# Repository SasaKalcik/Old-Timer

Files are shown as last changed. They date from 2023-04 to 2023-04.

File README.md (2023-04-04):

# Old-Timer

## 3D printed Arduino based interval timer display
Old Timer is a 3D printed wall mountable interval timer, intented for HIIT (High Intensity Interval Training). This is a DIY-project for a 64x64 RGB LED matrix display with a speaker and an interface, powered by an Arduino microcontroller board.

[VIDEO](https://youtu.be/OxGpQ27moh4)

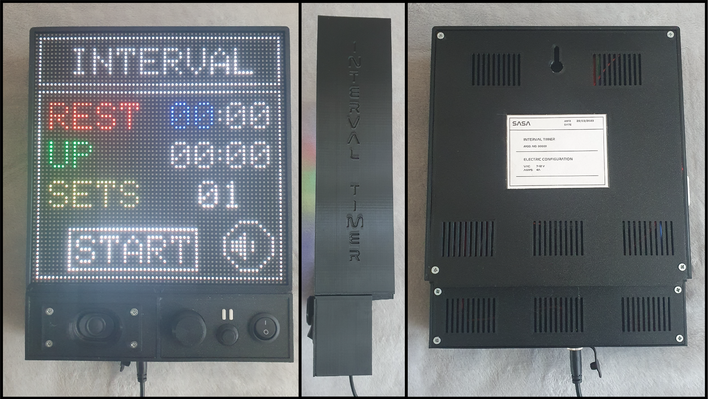
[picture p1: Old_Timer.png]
Old Timer


## Hardware
This project started out with parts from an Arduino starter kit, 3D printed parts and a 64x64 RGB LED matrix. For an affordable minimalistic parts list (without the 3D printed case) I would recommend the following:

- 1 x AC-DC power adapter 5.0 V / 4.0 A  
- 1 x ELEGOO Mega R3 2560 Project Starter Kit 
- 1 x (64x64) RGB LED matrix
- 1 x DFPlayer mini MP3 player
- 1 x TF-card (DFPlayer supports up to: 32 GB)

Complete list of Old Timer's "electronic guts":

- 1 x AC-DC power adapter 5.0 V / 4.0 A  
- 1 x Female DC Threaded Barrel Jack Panel Adapter (or any connector suitable for plug of AC-DC power adapter)
- 1 x MEGA 2560 R3 Controller Board
- 1 x Prototype Shield Board Kit for Arduino Mega \*
- 1 x (64x64) RGB LED matrix 
- 1 x DFPlayer mini MP3 player
- 1 x TF-card (DFPlayer supports up to: 32 GB)
- 1 x 3 W 8 &Omega; Speaker 
- 1 x rotary encoder with switch function (on press down)
- 1 x tactile switch (6 x 6 x 4.3 mm) 
- 1 x ON/OFF toggle round rocker switch 
- 1 x 1 k&Omega; resistor
- DuPont cables

\* *Note: The stock shield board kit for the Arduino Mega has female pins for DuPont cable connections. These can be desoldered and replaced with male pin connectors, since the DATA IN cable of the RGB LED matrix board comes with a female to female pin cable. Alternatively you can use DuPont cable connections and ommit the shield altogether. Also the FDPlayer can be mounted on the shield.*

## 3D printed case

The 3D printed case printed with PLA filament is split into a top and lower part. The top part is connected with the matrix display with 6 (M3 x 10 mm) screw bolts (red dots in the picture). The matrix display provides the structural strength, so the case walls can be very thin (2 - 3 mm). The lower body containing the speaker and buttons can be swapped/upgraded in the future. The bottom and top bodies are connected with 6 (M4 x 15 mm) screw bolts and M4 hex nuts (green dots in the picture). The case is sealed with two covers which can be screwed on using 8 (M3 x 10 mm) bolts (red dots in the picture). There is a mount for the Arduino board and a cover for the speaker which also can be fastened with (M3 x 10 mm) screw bolts. I have also made a case for the mini switch button (4 parts). It's a cheap alternative to buying a switch button with housing. The top part of the button can be screwed on the housing containing the mini switch to make a nice clicking action. Two hex nuts can be printed instead of one to better secure the housing and top part of the button. 

3D printed case assembly parts:

- [8 x 3D printed parts](/STL_files) 
- 23 x (M3 x 10 mm) screw bolts 
- 6 x (M4 x 15 mm) screw bolts
- 6 x (M4 9 mm diameter) flat washers 
- 6 x M4 hex nuts

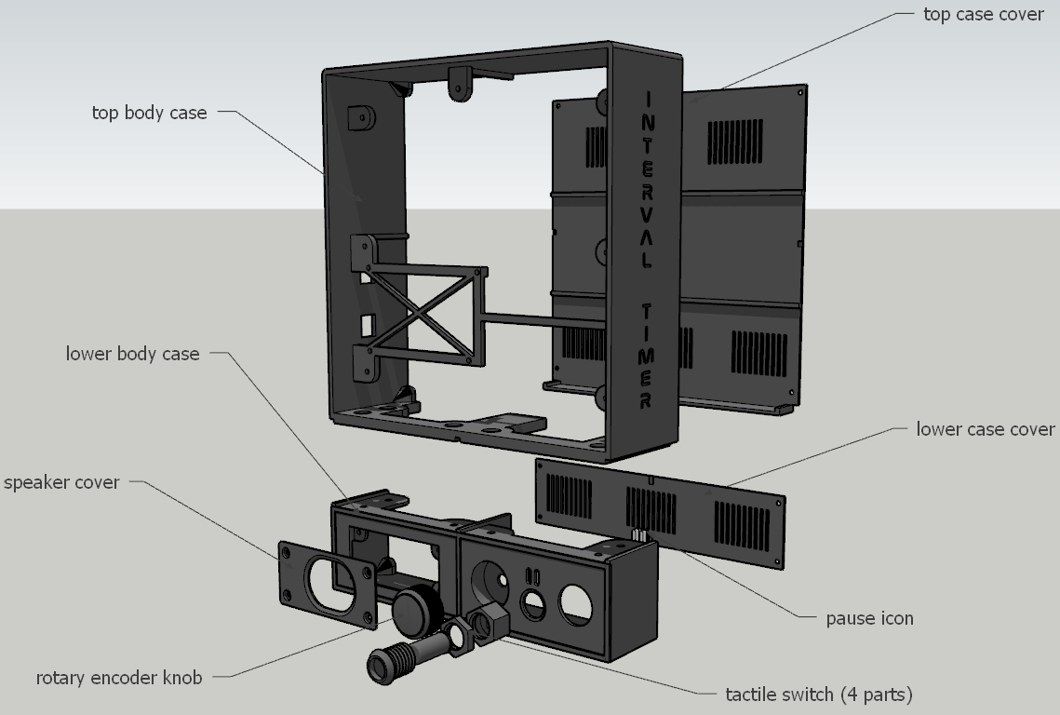
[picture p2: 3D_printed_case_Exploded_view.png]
exploded view of 3D printed case


## Wiring 

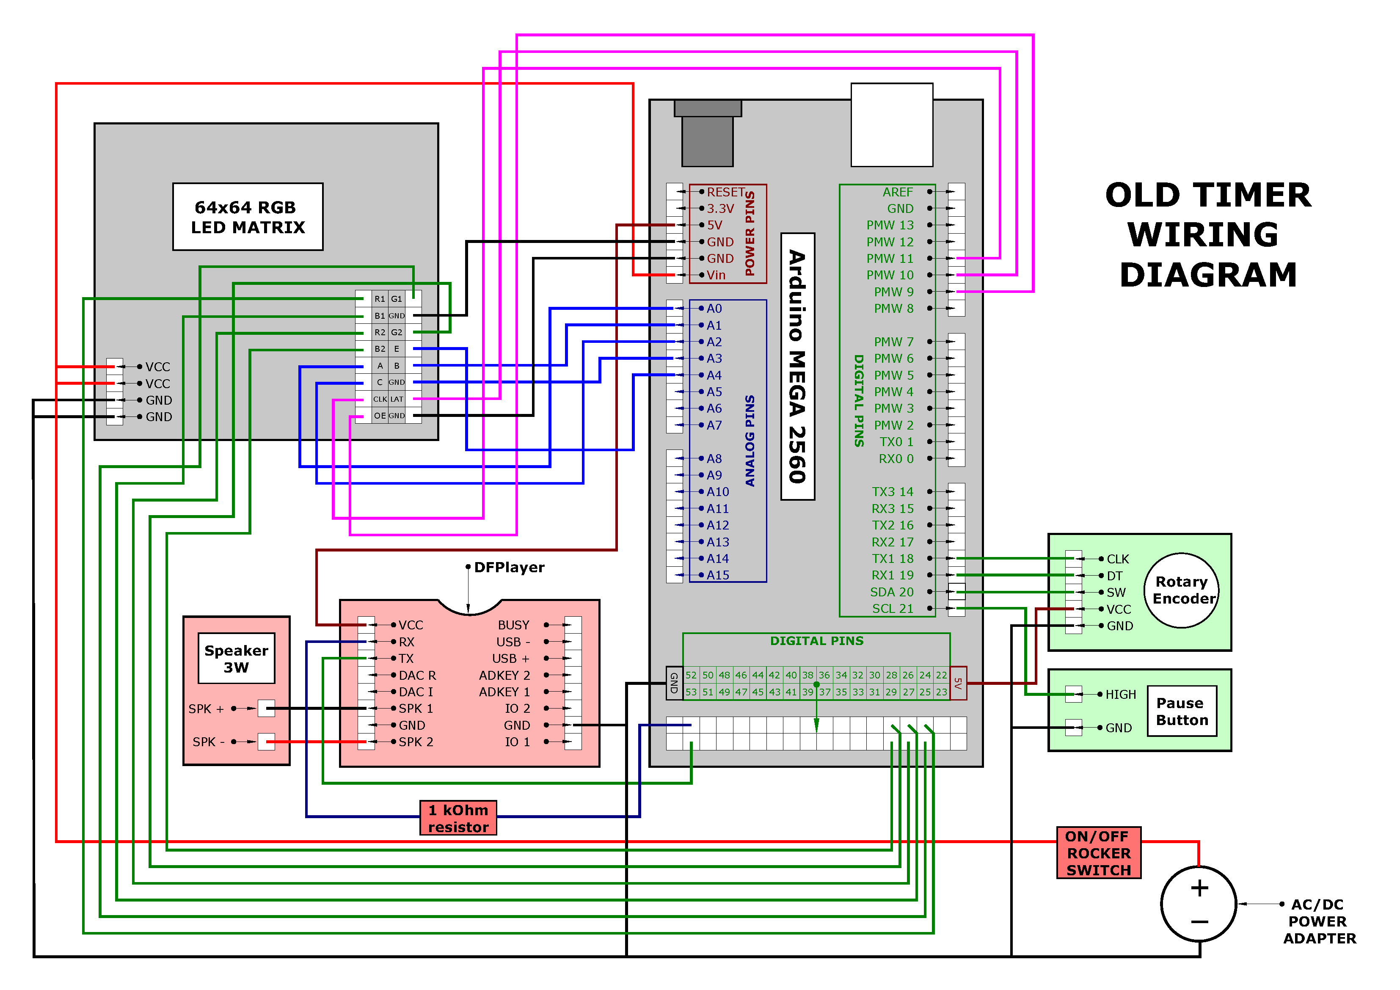
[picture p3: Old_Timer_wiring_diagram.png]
Old Timer wiring diagram


For clarity the wiring can be split down into serveral parts:

### Power supply
The 64x64 RGB LED matrix alone requires a 5 V regulated DC power input and 4 A with all LEDs on at full brightness. However, a 5V 4A is sufficient to power to entire setup. For testing, the Arduino controller board can be powered directly from a computer using an USB connector without an external power supply. An ON/OFF toggle round rocker switch is added to switch the power supply on and off. 

### RGB LED Matrix 
The 64x64 RGB LED Matrix Panel has 4096 full-color RGB LEDs, which can be controlled independently. These kind of displays are designed to be driven by FPGAs (field-programmable gate arrays) and dont have any built in pulse-width modulation control. An Arduino MEGA 2560 R3 Controller Board is used since the RGB LED display needs 13 GPIOs (general-purpose input/output pins) to be controlled. Other microcontrollers (Raspberry Pi) with large enough speed and memory can be used. The Mega 2560 works great for this project, but higher speed controllers are needed to drive this display in "full glory". Alternatively smaller LED Matrix displays are available (for example a 1024 bright RGB LED display on a 32x32 grid). The matrix panel has two IDC (insulation-displacement contact) connectors DATA IN and DATA OUT to cascade displays. The Arduino isn't powerful enough however to control larger displays.

DATA IN IDC signal pins connected to Arduino MEGA 2560, L if left and R is right side of connector pins:

|DATA IN L|Arduino pins| DATA IN R|Arduino pins|
|:---:|:---:|:---:|:---:|
|R1|24|G1|25|
|B1|26|GND|GND|
|R2|27|G2|28|
|B2|29|E|A4|
|A|A0|B|A1|
|C|A2|D|A3|
|CLK|11|LAT|10|
|OE|9|GND|GND|

Power interface:
|RGB LED Matrix|AC-DC power adapter|
|:---:|:---:|
|2 x +5V | positive terminal|
|2 x GND | negative terminal|

### Interrupts: rotary encoder and push buttons

The interface of the interval timer is a rotary encoder and a push switches. The rotart enocoder has a built in push switch, which is used to navigate the menu. A mini tactile switch serves to pause the interval timer. Both inputs are connect via interrupt pins to the Arduino. Pins 2,3,18,19,20,21 can be used on the Arduino Mega 2560 as external interrupt pins.

|rotary encoder|mini push switch|
|--|--|
|<table> <tr><th>pin</th><th>Arduino</th></tr><tr><td>CLK</td><td>18</td></tr><tr><td>DT</td><td>19</td></tr><tr><td>SW</td><td>20</td></tr><tr><td>VCC</td><td>5V</td></tr><tr><td>GND</td><td>GND</td></tr></table>|<table><tr><th>pin</th><th>Arduino</th></tr><tr><td>HIGH</td><td>21</td></tr><tr><td>GND</td><td>GND</td></tr></table>|

### DFPlayer mini MP3 player

The DFPlayer is a MP3 player module with a TF card/MicroSD slot. The MP3 player can be powered by the 3.3 V or 5 V output of the Arduino. After testing the DFPlayer module in a mono circuit with a 3 W 8 &Omega; speaker-setup I found that module doesn't work reliably with 3.3 V input. With 5 V input, the Arduino doesn't seem to provide enough current when changing the volume to max. I've ordered and tested three MP3 modules. Two modules worked perfect, one was faulty. An external power supply with a max voltage of 5 V is ideal to reduce noise and increase the power from the speaker. However it is not necessary since the MP3 player won't be operating at max volume for an extented period of time in this project. I would recommend ordering a few MP3 player modules to serve as backup, since they are very cheap. The DFPlayer  has a 3 W amplifier. A speaker with 4 &Omega; or more impedance can also be used for a louder maximum volume.

The pins on the DFPlayer are not indicated so be mindful of the orientation. The signal pins of the DFPlayer mini module are not 5V tolerant so a voltage divider (1 k&Omega; resistor) is added between the RX signal pin and the Arduino. 

The DFPLayer pins connected to the Arduino:

|DFLPLayer|Arduino|
|:---:|:---:|
|VCC|5V|
|RX|52|
|TX|53|
|SPK1|SPK+|
|GND|GND|
|SPK2|SPK-|

## Code

The [code](/Old_Timer.ino) for the interval timer is for a menu system. [Here](https://youtu.be/OxGpQ27moh4) is a video of the Old Timer in action. 

When turned on a startup animation plays and a menu is displayed. In this menu you can set the following:

- UP, duration of workout in minutes and seconds
- REST, duration of rest in minutes and seconds
- SETS, the number of sets of UP/REST 
- Volume of the speaker (0 - 30)

After the everything is set, START is pressed --> interval cycles are run --> return to the selection menu. 

Detailed comments are provided in the code, but I'll quickly run throught the code. You will need several libraries for the display and MP3 player:

- Graphics library for the RGB LED matrix: [DFRobot_RGBMatrix.h](https://github.com/DFRobot/DFRobot_RGBMatrix)
- library for MP3 player: [DFRobotDFPlayerMini.h](https://github.com/DFRobot/DFRobotDFPlayerMini)  
- library for serial communication: [SoftwareSerial.h](https://docs.arduino.cc/learn/built-in-libraries/software-serial)
- library for I2C communication: [Wire.h](https://www.arduino.cc/reference/en/language/functions/communication/wire/)
- library for calculation: [math.h](https://www.tutorialspoint.com/arduino/arduino_math_library.htm)

The *loop()* function waits for interrupts from the rotary encoder : *read_encoder()* and *buttonPush_encoder()*. It checks whether the cursor postion is changed through rotation of the encoder: *refreshMATRIX == true*. The loop also checks for the selection of a menu item due to a button push: *refreshSelection == true*.

```ruby
void loop() 
{
  if(refreshMATRIX == true) 
  {
    updateMATRIX(); 
    if(menu_RESTm_selected == true...) // refresh cursor on interrupt
    {
     // do nothing if no menu item is selected
    }
    else
    {
      updateCursorPosition(); 
    }
    refreshMATRIX = false; 
  }

  if(refreshSelection == true) // refresh selection on interrupt
  {
    updateSelection(); 
    refreshSelection = false; 
  }
}
```

The functions: *updateCursorPosition()*, *updateSelection* and *updateMATRIX* then update the display by updating a part of the screen. The display resfreshes much smoother by updating parts of the matrix than rewriting the entire screen, since these RGB LED matrix displays usually are driven by FPGAs. 

Finally I have written functions which display time (*printTime*), loading bars (*loadingBar*), the full interval cycle (*intervalTimerScreen*) and text (*displayText*). These function use the DFRobot_RGBMatrix grahpics library and comments are provided in the [code](/Old_Timer.ino).

## Credits and References

This project wouldn't have been possible without the amazing tutorials and projects available online. So I would like to thank everyone for all the great idea's and information. I'm happy to share their links as a shout-out:

[Wiring DFPlayer Mini](https://circuitjournal.com/how-to-use-the-dfplayer-mini-mp3-module-with-an-arduino)

[DFR0499 64x64 RGB LED matrix](https://wiki.dfrobot.com/64x64_RGB_LED_Matrix_-_3mm_pitch_SKU_DFR0499)

[Advanced menu system with rotary encoder for Arduino/STM32](https://www.youtube.com/watch?v=CnS0PuDJybA&t=323s&ab_channel=CuriousScientist)

[Arduino Button Debounce Tutorial](https://www.youtube.com/watch?v=jYOYgU2vlSE&ab_channel=educ8s.tv)

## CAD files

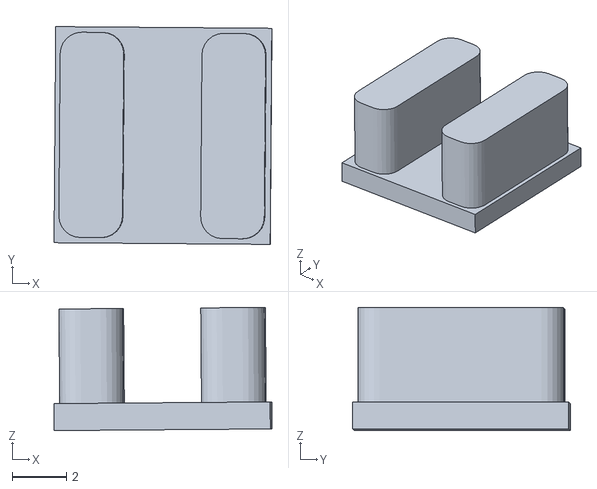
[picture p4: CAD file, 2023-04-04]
STL_files/pause_button.stl
8.07 x 8.06 x 4.56

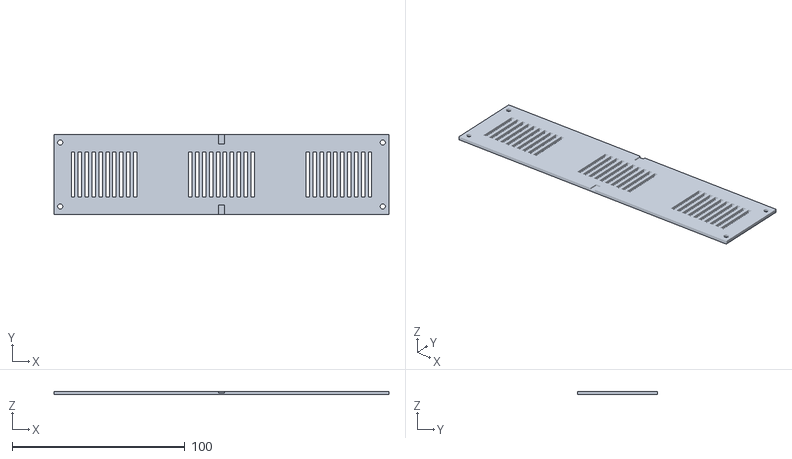
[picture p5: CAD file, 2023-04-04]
STL_files/lower_case_cover.stl
194.0 x 46.2 x 2.00

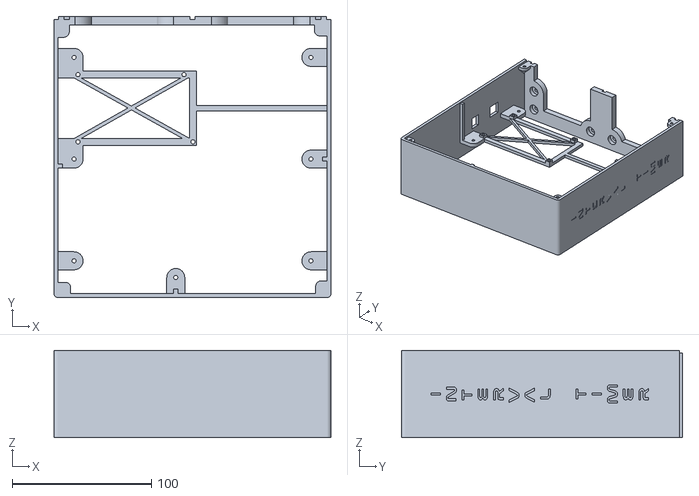
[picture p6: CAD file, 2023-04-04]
STL_files/top_body_case.stl
198.8 x 201.8 x 62.5

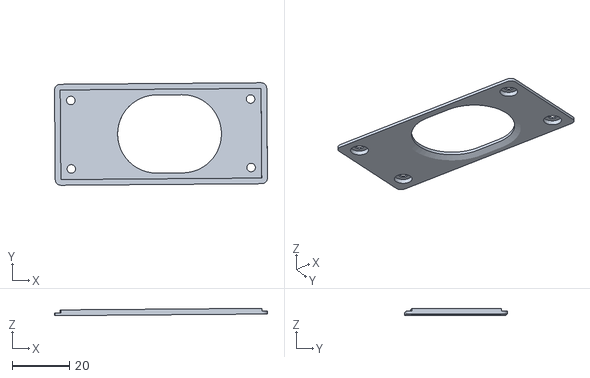
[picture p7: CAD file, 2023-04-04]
STL_files/speaker_cover.stl
74.6 x 35.9 x 2.56

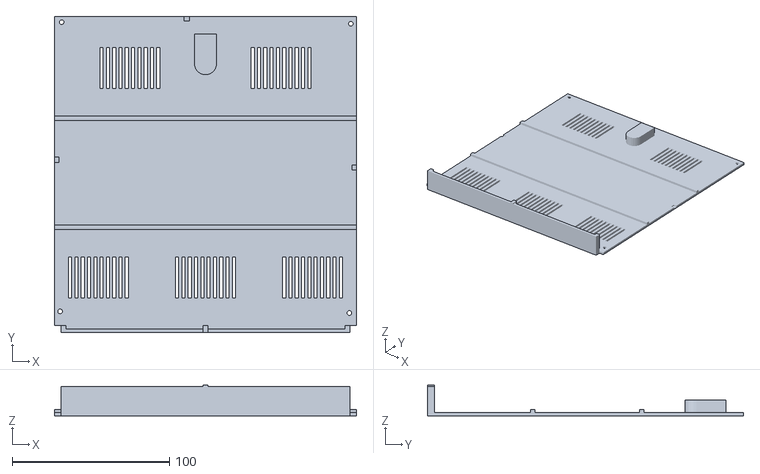
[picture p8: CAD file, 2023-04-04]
STL_files/top_case_cover.stl
192.0 x 200.8 x 19.5

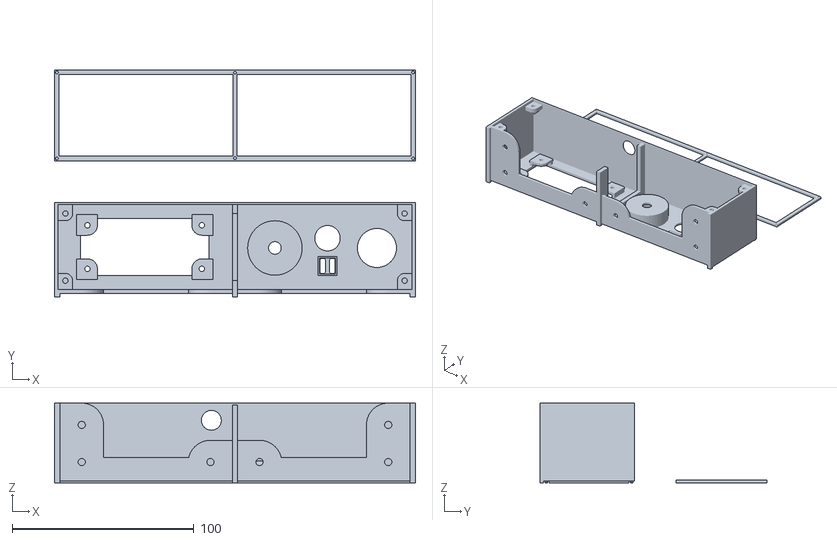
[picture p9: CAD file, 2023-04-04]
STL_files/lower_body_case.stl
198.8 x 125.0 x 44.0

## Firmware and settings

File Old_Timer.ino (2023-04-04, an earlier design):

// libraries
#include <DFRobot_RGBMatrix.h>    // graphics library for RGB LED matrix board
#include <Wire.h>                 // library for I2C communication
#include <math.h>                 // library for calculations
#include <DFRobotDFPlayerMini.h>  // library for MP3 player
#include <SoftwareSerial.h>       // library for serial communication

// Defining MATRIX BOARD pins and variables connected to elegoo mega 2560 
#define OE    9                 // Output enable
#define LAT   10                // Latch
#define CLK   11                // Clock
#define A     A0                // A line selection
#define B     A1                // B line selection
#define C     A2                // C line selection
#define D     A3                // D line selection
#define E     A4                // ground?
#define WIDTH 64                // matrix board 64 px width
#define HIGH  64                // matrix board 64 px height
// set MATRIX BOARD pin settings & size
DFRobot_RGBMatrix matrix(A, B, C, D, E, CLK, LAT, OE, false, WIDTH, HIGH); 

// Define ROTARY ENCODER pins
// Note: Arduino MEGA 2560 interrupt pins: 2, 3, 18,19,20,21 (20,21 not available when I2C is used)
#define ENC_CLK 18            // encoder CLK used for rotation and diretion detection
#define ENC_DT 19             // encoder DT used for rotation and diretion detection
#define ENC_SW 20             // Click Button
#define BTN_Pause 21          // Pause Button
// Statuses for the ROTARY ENCODER
unsigned long _lastIncReadTime = micros(); 
unsigned long _lastDecReadTime = micros(); 
int _pauseLength = 25000;
int _fastIncrement = 5;
volatile int counter = 0;

// Define MP3 player pins and create object for MP3 player
SoftwareSerial mySoftwareSerial(53, 52);  // (TX, RX)
DFRobotDFPlayerMini MP3_Player;           // create MP3_Player object

// MENU variables
// Note: if menu item is selected/deselected colour changes blue/white
int8_t menuCounter = 0;            // counts menu items (0-6) = (RESTm,RESTs,UPm,Ups,SETS,START,VOLUME)
int8_t menu_RESTm_Value = 0;       // rest minutes (0-59)
int8_t menu_RESTs_Value = 0;       // rest seconds (0-59)
int8_t menu_UPm_Value = 0;         // UP minutes (0-59)
int8_t menu_UPs_Value = 0;         // UP seconds (0-59)
int8_t menu_SETS_Value = 1;        // number of sets (1-99)
int8_t menu_start_Value = 0;       // start button
int8_t menu_volume_Value = 20;     // volume (0/10/20/30)
volatile bool flagPause;           // pause button flag

int8_t menu_RESTm_Value_old = menu_RESTm_Value;       // rest minutes (0-59)
int8_t menu_RESTs_Value_old = menu_RESTs_Value;       // rest seconds (0-59)
int8_t menu_UPm_Value_old = menu_UPm_Value;           // UP minutes (0-59)
int8_t menu_UPs_Value_old = menu_UPs_Value;           // UP seconds (0-59)
int8_t menu_SETS_Value_old = menu_SETS_Value;         // number of sets (1-99)
int8_t menu_start_Value_old = menu_start_Value;       // start button
int8_t menu_volume_Value_old = menu_volume_Value;     // volume (0/10/20/30)

// enable/disable selected menu item on start up
bool menu_RESTm_selected = false;   
bool menu_RESTs_selected = false;
bool menu_UPm_selected = false;
bool menu_UPs_selected = false;
bool menu_SETS_selected = false;
bool menu_start_selected = false;
bool menu_volume_selected = false;
bool refreshMATRIX = true;      // refreshes display on startup
bool refreshSelection = false;  // refreshes selection (white to blue) on start up

void setup() 
{
  // Steer input pin to known state using built in pullup 20 k Ohm resistor
  pinMode(ENC_CLK, INPUT_PULLUP);   // RotaryCLK
  pinMode(ENC_DT, INPUT_PULLUP);    // RotaryDT
  pinMode(ENC_SW, INPUT_PULLUP);    // ButtonSW (Button)
  pinMode(BTN_Pause,INPUT_PULLUP);  // Pause Button

  // Attach interrupt pins    
  attachInterrupt(digitalPinToInterrupt(ENC_CLK), read_encoder, CHANGE);       
  attachInterrupt(digitalPinToInterrupt(ENC_DT), read_encoder, CHANGE);
  attachInterrupt(digitalPinToInterrupt(ENC_SW), buttonPush_encoder, FALLING);  
  attachInterrupt(digitalPinToInterrupt(BTN_Pause), buttonPush_Pause, FALLING);

  // Settings for MP3 player
  mySoftwareSerial.begin(9600);             // Initialize USB serial port for debugging
  Serial.begin(115200);                     // Initialize serial port for DFPlayer Mini
  if (MP3_Player.begin(mySoftwareSerial))   // Start communication with DFPlayer Mini
  { 
    Serial.println("MP3 Player Ready..."); 
    MP3_Player.EQ(5);                       // set equalizer to bass
    MP3_Player.volume(menu_volume_Value);   // set volume 0-30
  }
  else
  {
    Serial.println("Connecting to DFPlayer Mini failed!");
  }
  
  // Initiate LED matrix, display start screen & selection screen
  matrix.begin();                    // initialize matrix display 
  displayStartScreen();              // display start screen
  displaySelectionScreen();          // display selection screen

}
// 1. updates screen & cursor position with:  updateCursorPosition()
// 2. updates selected item with:             updateSelection()
void loop() 
{
  if(refreshMATRIX == true) // If we are allowed to update the MATRIX...
  {
    updateMATRIX(); // ... we update the MATRIX ...

    // ... also, if one of the menus are already selected...
    if(menu_RESTm_selected == true || menu_RESTs_selected == true || menu_UPm_selected == true || menu_UPs_selected == true || menu_SETS_selected == true || menu_start_selected == true)
    {
     // do nothing
    }
    else
    {
      updateCursorPosition(); // update the position
    }
    
    refreshMATRIX = false; // reset the variable - wait for a new trigger
  }

  if(refreshSelection == true) // if the selection is changed
  {
    updateSelection(); // update the selection on the MATRIX
    refreshSelection = false; // reset the variable - wait for a new trigger
  }
  
}
// change menu_item_selected on button press
void buttonPush_encoder()
{
  static unsigned long last_interrupt_time = 0;
  unsigned long interrupt_time = millis();
  // If interrupts is faster than 200ms, assume it's a bounce and ignore
  if (interrupt_time - last_interrupt_time > 200) 
  {
  switch(menuCounter)
  {
     case 0:
     menu_RESTm_selected = !menu_RESTm_selected;  // change the status of the variable to the opposite
     break;

     case 1:
     menu_RESTs_selected = !menu_RESTs_selected;
     break;

     case 2:
     menu_UPm_selected = !menu_UPm_selected;
     break;

     case 3:
     menu_UPs_selected = !menu_UPs_selected;
     break;

     case 4:
     menu_SETS_selected = !menu_SETS_selected;
     break;

     case 5:
     menu_start_selected = !menu_start_selected;
     break;

     case 6:
     menu_volume_selected = !menu_volume_selected;
     break;
  } 
  refreshMATRIX = true; // Refresh MATRIX after changing the value of the menu items
  refreshSelection = true; // refresh the selection
  }
  last_interrupt_time = interrupt_time;
}
// pause during countdown
void buttonPush_Pause()
{
  static unsigned long last_interrupt_time = 0;
  unsigned long interrupt_time = millis();
  // If interrupts is faster than 200ms, assume it's a bounce and ignore
  if (interrupt_time - last_interrupt_time > 200) 
  {
    flagPause = !flagPause;
  }
  last_interrupt_time = interrupt_time;
}
// actions when encoder is rotated
void read_encoder()
{  
  //-----MENU REST minutes DISPLAY--------------------------------------------------------------
  if(menu_RESTm_selected == true)
  {
    // Encoder interrupt routine for both pins. Updates counter
    // if they are valid and have rotated a full indent
    static uint8_t old_AB = 3;  // Lookup table index (3 corresponds to "00000011" so A == (ENC_CLK) && B == (ENC_DT) are high)
    static int8_t encval = 0;   // Encoder value  
    static const int8_t enc_states[]  = {0,-1,1,0,1,0,0,-1,-1,0,0,1,0,1,-1,0}; // Lookup table

    old_AB <<=2;  // Remember previous state (shift 2 places to left) 
    // NOTE: to switch direction change ENC_DT with ENC_CLK below so A becomes B & B becomes A
    if (digitalRead(ENC_DT)) old_AB |= 0x02;   // Add current state of pin A 
    if (digitalRead(ENC_CLK)) old_AB |= 0x01;    // Add current state of pin B
    encval += enc_states[( old_AB & 0x0f )];    // convert encval e.g. : "xxxxyyyyy" to "0000yyyy" to use enc_states[] properly

    // Update counter if encoder has rotated a full indent, that is at least 4 steps
    if( encval > 3 )    // Four steps forward----------------------------------
    {        
      int changevalue = 1;
      if((micros() - _lastIncReadTime) < _pauseLength) 
      {
        changevalue = _fastIncrement * changevalue;   // if rotation is faster changevalue is larger
      }
      _lastIncReadTime = micros();           
      if(counter <59) // do not go above 59
      {
        counter = counter + changevalue;  // Update counter
      }
      else
      {
        counter = 0;  
      }  
      menu_RESTm_Value = counter;
      encval = 0;
      refreshMATRIX = true;
    }
    else if( encval < -3 )  // Four steps backward------------------------------
    {        
      int changevalue = -1;
      if((micros() - _lastDecReadTime) < _pauseLength) 
      {
        changevalue = _fastIncrement * changevalue; 
      }
      _lastDecReadTime = micros();
      if(counter < 1) // do not go below 0
      {
        counter = 59; // changes to 0 in next cycle of loop
      }
      else
      {
      // Encoder is rotating B direction so decrease
      counter = counter + changevalue;              // Update counter      
      }  
      menu_RESTm_Value = counter;
      encval = 0;
      refreshMATRIX = true;
    }
  }
  //---MENU REST seconds DISPLAY---------------------------------------------------------------
  else if(menu_RESTs_selected == true)
  {
    static uint8_t old_AB = 3;
    static int8_t encval = 0; 
    static const int8_t enc_states[]  = {0,-1,1,0,1,0,0,-1,-1,0,0,1,0,1,-1,0};
    
    old_AB <<=2;
    if (digitalRead(ENC_DT)) old_AB |= 0x02;   
    if (digitalRead(ENC_CLK)) old_AB |= 0x01;    
    encval += enc_states[( old_AB & 0x0f )];    

    if( encval > 3 )    // Four steps forward----------------------------------
    {        
      int changevalue = 1;
      if((micros() - _lastIncReadTime) < _pauseLength) 
      {
        changevalue = _fastIncrement * changevalue;   
      }
      _lastIncReadTime = micros();           
      if(counter <59) // do not go above 59
      {
        counter = counter + changevalue;  // Update counter
      }
      else
      {
        counter = 0;  
      }  
      menu_RESTs_Value = counter;
      encval = 0;
      refreshMATRIX = true;
    }
    else if( encval < -3 )  // Four steps backward------------------------------
    {        
      int changevalue = -1;
      if((micros() - _lastDecReadTime) < _pauseLength) 
      {
        changevalue = _fastIncrement * changevalue; 
      }
      _lastDecReadTime = micros();
      if(counter < 1) // do not go below 0
      {
        counter = 59; // changes to 0 in next cycle of loop
      }
      else
      {
      // Encoder is rotating B direction so decrease
      counter = counter + changevalue;              // Update counter      
      }  
      menu_RESTs_Value = counter;
      encval = 0;
      refreshMATRIX = true;
    }
  }
  //---MENU UP minutes DISPLAY---------------------------------------------------------------
  else if(menu_UPm_selected == true)
  {
    static uint8_t old_AB = 3;
    static int8_t encval = 0; 
    static const int8_t enc_states[]  = {0,-1,1,0,1,0,0,-1,-1,0,0,1,0,1,-1,0};
    
    old_AB <<=2;
    if (digitalRead(ENC_DT)) old_AB |= 0x02;   
    if (digitalRead(ENC_CLK)) old_AB |= 0x01;    
    encval += enc_states[( old_AB & 0x0f )];    

    if( encval > 3 )    // Four steps forward----------------------------------
    {        
      int changevalue = 1;
      if((micros() - _lastIncReadTime) < _pauseLength) 
      {
        changevalue = _fastIncrement * changevalue;   
      }
      _lastIncReadTime = micros();           
      if(counter <59) // do not go above 59
      {
        counter = counter + changevalue;  // Update counter
      }
      else
      {
        counter = 0;  
      }  
      menu_UPm_Value = counter;
      encval = 0;
      refreshMATRIX = true;
    }
    else if( encval < -3 )  // Four steps backward------------------------------
    {        
      int changevalue = -1;
      if((micros() - _lastDecReadTime) < _pauseLength) 
      {
        changevalue = _fastIncrement * changevalue; 
      }
      _lastDecReadTime = micros();
      if(counter < 1) // do not go below 0
      {
        counter = 59; // changes to 0 in next cycle of loop
      }
      else
      {
      // Encoder is rotating B direction so decrease
      counter = counter + changevalue;              // Update counter      
      }  
      menu_UPm_Value = counter;
      encval = 0;
      refreshMATRIX = true;
    }
  }
  //---MENU UP seconds DISPLAY---------------------------------------------------------------
  else if(menu_UPs_selected == true)
  {
    static uint8_t old_AB = 3;
    static int8_t encval = 0; 
    static const int8_t enc_states[]  = {0,-1,1,0,1,0,0,-1,-1,0,0,1,0,1,-1,0};
    
    old_AB <<=2;
    if (digitalRead(ENC_DT)) old_AB |= 0x02;   
    if (digitalRead(ENC_CLK)) old_AB |= 0x01;    
    encval += enc_states[( old_AB & 0x0f )];    

    if( encval > 3 )    // Four steps forward----------------------------------
    {        
      int changevalue = 1;
      if((micros() - _lastIncReadTime) < _pauseLength) 
      {
        changevalue = _fastIncrement * changevalue;   
      }
      _lastIncReadTime = micros();           
      if(counter <59) // do not go above 59
      {
        counter = counter + changevalue;  // Update counter
      }
      else
      {
        counter = 0;  
      }  
      menu_UPs_Value = counter;
      encval = 0;
      refreshMATRIX = true;
    }
    else if( encval < -3 )  // Four steps backward------------------------------
    {        
      int changevalue = -1;
      if((micros() - _lastDecReadTime) < _pauseLength) 
      {
        changevalue = _fastIncrement * changevalue; 
      }
      _lastDecReadTime = micros();
      if(counter < 1) // do not go below 0
      {
        counter = 59; // changes to 0 in next cycle of loop
      }
      else
      {
      // Encoder is rotating B direction so decrease
      counter = counter + changevalue;              // Update counter      
      }  
      menu_UPs_Value = counter;
      encval = 0;
      refreshMATRIX = true;
    }
  }
  //---MENU SETS DISPLAY---------------------------------------------------------------
  else if(menu_SETS_selected == true)
  {
    static uint8_t old_AB = 3;
    static int8_t encval = 0; 
    static const int8_t enc_states[]  = {0,-1,1,0,1,0,0,-1,-1,0,0,1,0,1,-1,0};
    
    old_AB <<=2;
    if (digitalRead(ENC_DT)) old_AB |= 0x02;   
    if (digitalRead(ENC_CLK)) old_AB |= 0x01;    
    encval += enc_states[( old_AB & 0x0f )];    

    if( encval > 3 )    // Four steps forward----------------------------------
    {        
      int changevalue = 1;
      if((micros() - _lastIncReadTime) < _pauseLength) 
      {
        changevalue = _fastIncrement * changevalue;   
      }
      _lastIncReadTime = micros();           
      if(counter <99) // do not go above 99
      {
        counter = counter + changevalue;  // Update counter
      }
      else
      {
        counter = 1;  
      }  
      menu_SETS_Value = counter;
      encval = 0;
      refreshMATRIX = true;
    }
    else if( encval < -3 )  // Four steps backward------------------------------
    {        
      int changevalue = -1;
      if((micros() - _lastDecReadTime) < _pauseLength) 
      {
        changevalue = _fastIncrement * changevalue; 
      }
      _lastDecReadTime = micros();
      if(counter < 2) // do not go below 1
      {
        counter = 99; // changes to 99 in next cycle of loop
      }
      else
      {
      // Encoder is rotating B direction so decrease
      counter = counter + changevalue;              // Update counter      
      }  
      menu_SETS_Value = counter;
      encval = 0;
      refreshMATRIX = true;
    }
  }
  //---MENU START DISPLAY---------------------------------------------------------------
  else if(menu_start_selected == true)
  {
    // do nothing
  }
  //---MENU Volume DISPLAY---------------------------------------------------------------
 else if(menu_volume_selected == true)
  {
    static uint8_t old_AB = 3;
    static int8_t encval = 0; 
    static const int8_t enc_states[]  = {0,-1,1,0,1,0,0,-1,-1,0,0,1,0,1,-1,0};
    
    old_AB <<=2;
    if (digitalRead(ENC_DT)) old_AB |= 0x02;   
    if (digitalRead(ENC_CLK)) old_AB |= 0x01;    
    encval += enc_states[( old_AB & 0x0f )];    

    if( encval > 3 )    // Four steps forward----------------------------------
    {        
      int changevalue = 5;
      if((micros() - _lastIncReadTime) < _pauseLength) 
      {
        changevalue = _fastIncrement * changevalue;   
      }
      _lastIncReadTime = micros();           
      if(counter <30) // do not go above 30
      {
        counter = counter + changevalue;  // Update counter
      }
      else
      {
        counter = 30;  
      }  
      menu_volume_Value = counter;
      encval = 0;
      refreshMATRIX = true;
    }
    else if( encval < -3 )  // Four steps backward------------------------------
    {        
      int changevalue = -5;
      if((micros() - _lastDecReadTime) < _pauseLength) 
      {
        changevalue = _fastIncrement * changevalue; 
      }
      _lastDecReadTime = micros();
      if(counter < 1) // do not go below 1
      {
        counter = 0; // changes to 30 in next cycle of loop
      }
      else
      {
      // Encoder is rotating B direction so decrease
      counter = counter + changevalue;              // Update counter      
      }  
      menu_volume_Value = counter;
      encval = 0;
      refreshMATRIX = true;
    }
  }
  //---MENU COUNTER---------------------------------------------------------------
  else
  {
    static uint8_t old_AB = 3;
    static int8_t encval = 0; 
    static const int8_t enc_states[]  = {0,-1,1,0,1,0,0,-1,-1,0,0,1,0,1,-1,0};
    
    old_AB <<=2;
    if (digitalRead(ENC_DT)) old_AB |= 0x02;   
    if (digitalRead(ENC_CLK)) old_AB |= 0x01;    
    encval += enc_states[( old_AB & 0x0f )];    

    if( encval > 7 )    // Four steps forward----------------------------------
    {        
      int changevalue = 1;
      if(counter < 6) // do not go above 6
      {
        counter = counter + changevalue;  // Update counter
      }
      else
      {
        counter = 0;  
      }  
      menuCounter = counter;
      encval = 0;
      refreshMATRIX = true;
    }
    else if( encval < -7 )  // Four steps backward------------------------------
    {        
      int changevalue = -1;
      if(counter < 1) // do not go below 0
      {
        counter = 6; // changes to 0 in next cycle of loop
      }
      else
      {
      // Encoder is rotating B direction so decrease
      counter = counter + changevalue;              // Update counter      
      }  
      menuCounter = counter;
      encval = 0;
      refreshMATRIX = true;
    }
  }
  // Refresh MATRIX after changing the counter's value
  //refreshMATRIX = true;
}
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
